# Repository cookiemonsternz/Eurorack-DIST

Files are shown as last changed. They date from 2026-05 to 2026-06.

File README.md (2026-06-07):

# DIST
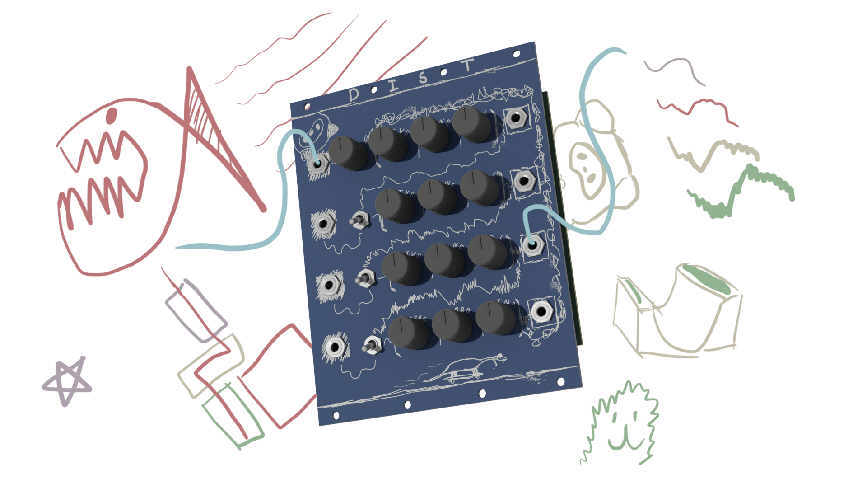
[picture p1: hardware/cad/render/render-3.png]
Render 3

_DIY multi-stage distortion Eurorack module, overdrive, distortion, fuzz, wrmergle, and any combination of them in one handy package_

#### What?
Where VCO was minimal, DIST is maximal! This is a module featuring four different distortion circuits, routed in series with inputs and outputs at every stage in the chain. The four circuits are:
1. Overdrive - Inspired by the Boss SD-1, but with a different tone section and diodes.
2. Distortion - Partly inspired by the RAT, again, many tweaks were made. 
3. Fuzz - Big Muff PI my beloved, slightly different architecture and transistors but still keeping the best tone section in effect I've seen.
4. Wrmergle - A fully custom, from scratch design based on internal feedback, with an adjustable noise gate for your convenience :)

Every circuit has a gain, tone, and volume control, as well as a switch deciding whether to take input from the previous section or from the input jack. The overdrive has a potentiometer instead of a switch, setting an overall feedback control for more fun effects.

#### Why?
Distortion is quite literally the best effect, but no one pedal gives quite enough for me lol. This module has various features which enable absolutely ridiculous gains, while still having some playability due to the noise gate. I also like the idea of having it patchable at any point, as it means you can pick and choose how much distortion (and of what types) you want, or even just use it as 4 seperate distortions in parallel. 

Its definitely a big module, but you do get an absolute crapton of features and control, which is always nice to have.

#### How to use?
The jacks on the left side are the inputs, and on the right the corresponding outputs.
Each section is routed into the next, and you can toggle between using the input jack or the previous stage as input using the switch. The top left knob controls the overall feedback, as in how much of the output of the WRMERGLE stage goes to the input of the OD stage. 

Generally, you should be able to find your way around by following the signal path on the front board.

#### Simulations
I've included the simulations I created on LTSpice; *od.asc*, *dist.asc*, *fuzz.asc*, and *wrmergle.asc* contain their respective distortion stages, *gate.asc* contains the gate circuit of the WRMERGLE section, and *structure.asc* is a pseudo-layout of the whole circuit (not functional).

There is also a livespice simulation of the OVERDRIVE section, but I opted not to further utilise this tool due to lack of cross platform support and performance limitations.

I've also included some audio samples generated through LTSpice in **audio-samples/**, note that these are simulations and are thus not perfect, but they should be reasonably accurate.

## Renders
Render 1
Render 2
Board Front
Board Back
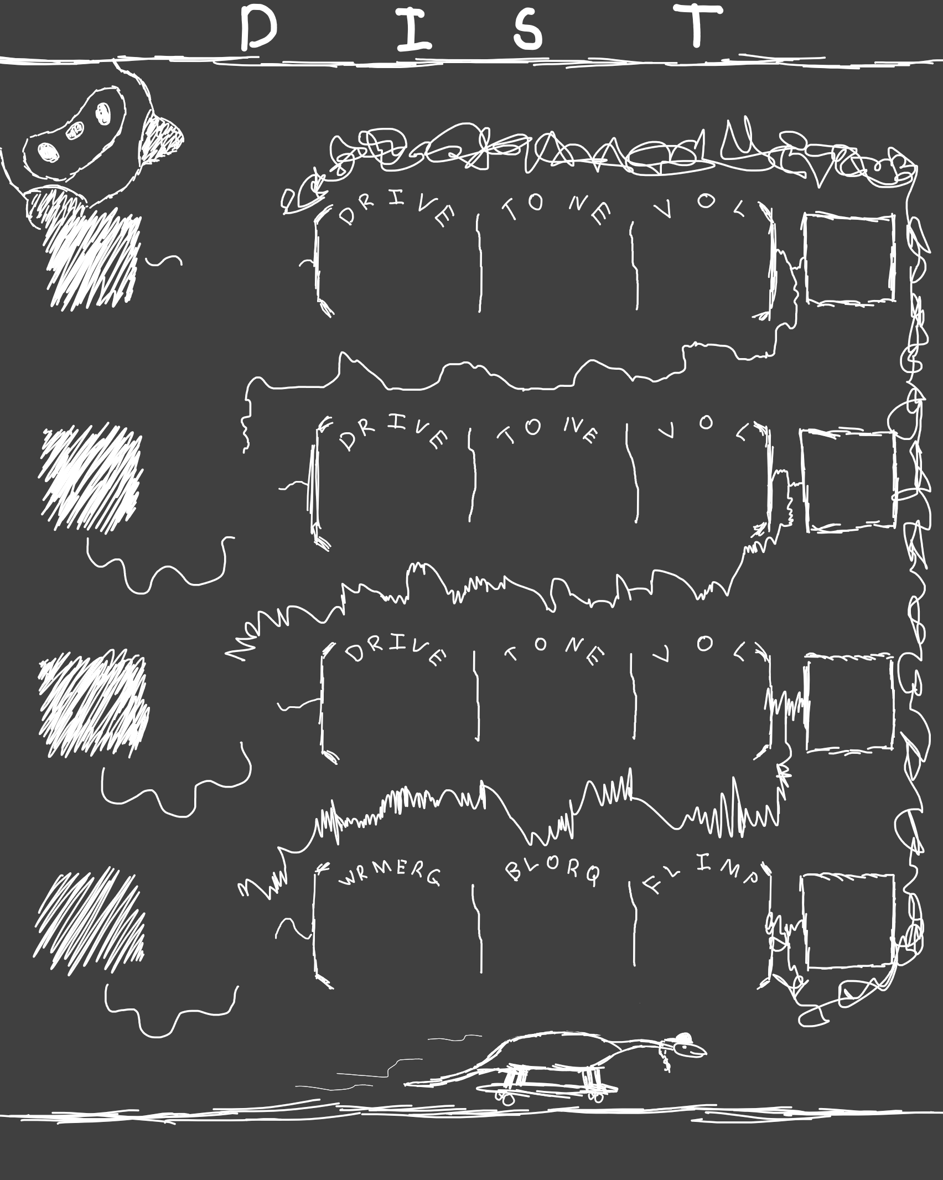
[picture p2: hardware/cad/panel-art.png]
Panel art


## Schematics
Main
OD
DIST
FUZZ
WRMERGLE

## Zine Page

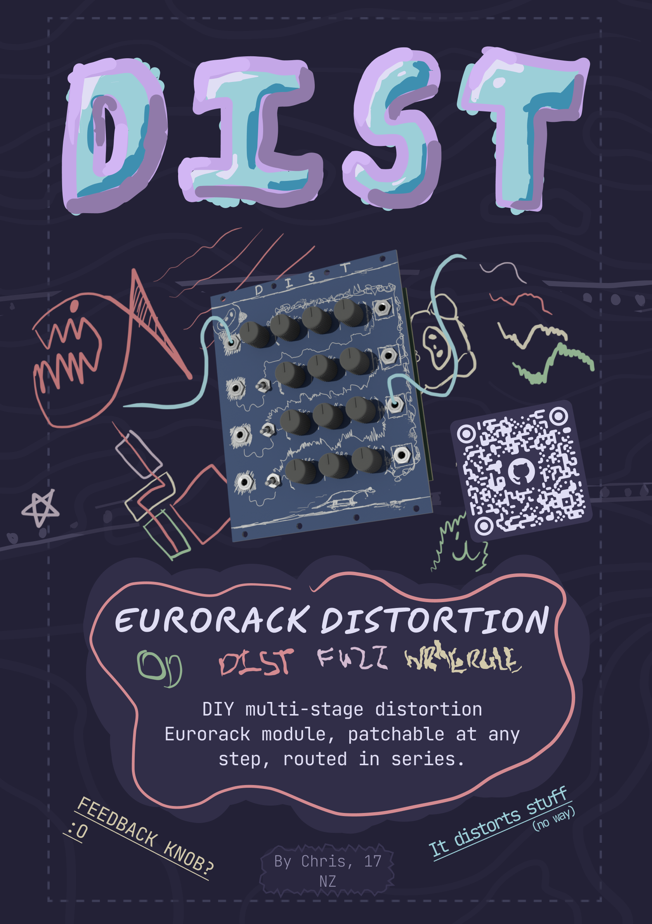
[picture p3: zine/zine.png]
Zine page


## BOM
_Needed is how many I personally need :)_
| Part | Quantity | Needed | Source | Link | Lot / Min Amount | Unit | Net | Running |
|---|---|---|---|---|---|---|---|---|
| **Capacitors** | | | | | | | | |
| 1n Cap, 0805 | 6 | 6 | JLCPCB | https://jlcpcb.com/partdetail/47657-CL21B102KBCNNNC/C46653 | 1 | $0.0112 | $0.0672 | $0.07 |
| 4.7n Cap, 0805 | 3 | 3 | JLCPCB | https://jlcpcb.com/partdetail/2096-0805B472K500NT/C1744 | 1 | $0.0066 | $0.0198 | $0.09 |
| 10n Cap, 0805 | 2 | 2 | JLCPCB | https://jlcpcb.com/partdetail/2062-CL21B103KBANNNC/C1710 | 1 | $0.0082 | $0.0164 | $0.10 |
| 22n Cap, 0805 | 2 | 2 | JLCPCB | https://jlcpcb.com/partdetail/2081-CL21B223KBANNNC/C1729 | 1 | $0.0097 | $0.0194 | $0.12 |
| 100n Cap, 0805 | 19 | 19 | JLCPCB | https://jlcpcb.com/partdetail/YAGEO-CC0805KRX7R9BB104/C49678 | 1 | $0.0066 | $0.1254 | $0.25 |
| 220n Cap, 0805 | 13 | 13 | JLCPCB | https://jlcpcb.com/partdetail/5810-CL21B224KBFNNNE/C5378 | 1 | $0.0122 | $0.1586 | $0.41 |
| 1u Cap, 0805 | 1 | 1 | JLCPCB | https://jlcpcb.com/partdetail/29074-CL21B105KBFNNNE/C28323 | 1 | $0.0165 | $0.0165 | $0.42 |
| 1u Electrolytic Cap, P1.5xD4.0 | 4 | 0 | LCSC | https://www.lcsc.com/product-detail/C216323.html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 | 50 | $0.0185 | $0.0000 | $0.42 |
| 2.2u Electrolytic Cap, P1.5xD4.0 | 1 | 0 | LCSC | https://www.lcsc.com/product-detail/C43343.html | 50 | $0.0151 | $0.0000 | $0.42 |
| 4.7u Electrolytic Cap, P1.5xD4.0 | 3 | 0 | LCSC | https://www.lcsc.com/product-detail/C2873979.html | 50 | $0.0114 | $0.0000 | $0.42 |
| 10u Electrolytic Cap, P1.5xD4.0  | 3 | 0 | LCSC | https://www.lcsc.com/product-detail/C503219.html | 50 | $0.0143 | $0.0000 | $0.42 |
| **Resistors** | | | | | | | | |
| 47? Resistor, 0805 | 2 | 2 | JLCPCB | https://jlcpcb.com/partdetail/18402-0805W8F470JT5E/C17714 | 1 | $0.002  | $0.0030 | $0.43 |
| 150? Resistor, 0805 | 2 | 2 | JLCPCB | https://jlcpcb.com/partdetail/18159-0805W8F1500T5E/C17471 | 1 | $0.0016 | $0.0032 | $0.43 |
| 560? Resistor, 0805 | 5 | 5 | JLCPCB | https://jlcpcb.com/partdetail/29388-0805W8F5600T5E/C28636 | 1 | $0.0019 | $0.0095 | $0.44 |
| 1k? Resistor, 0805 | 10 | 10 | JLCPCB | https://jlcpcb.com/partdetail/18201-0805W8F1001T5E/C17513 | 1 | $0.0021 | $0.0210 | $0.46 |
| 1.5k? Resistor, 0805 | 1 | 1 | JLCPCB | https://jlcpcb.com/partdetail/4717-0805W8F1501T5E/C4310 | 1 | $0.0015 | $0.0015 | $0.46 |
| 2.2k? Resistor, 0805 | 2 | 2 | JLCPCB | https://jlcpcb.com/partdetail/18208-0805W8F2201T5E/C17520 | 1 | $0.0015 | $0.0030 | $0.46 |
| 4.7k? Resistor, 0805 | 1 | 1 | JLCPCB | https://jlcpcb.com/partdetail/18361-0805W8F4701T5E/C17673 | 1 | $0.0016 | $0.0016 | $0.47 |
| 6.8k? Resistor, 0805 | 1 | 1 | JLCPCB | https://jlcpcb.com/partdetail/18460-0805W8F6801T5E/C17772 | 1 | $0.0017 | $0.0017 | $0.47 |
| 10k? Resistor, 0805 | 10 | 10 | JLCPCB | https://jlcpcb.com/partdetail/18102-0805W8F1002T5E/C17414 | 1 | $0.0020 | $0.0200 | $0.49 |
| 22k? Resistor, 0805 | 2 | 2 | JLCPCB | https://jlcpcb.com/partdetail/18248-0805W8F2202T5E/C17560 | 1 | $0.0027 | $0.0054 | $0.49 |
| 39k? Resistor, 0805 | 4 | 4 | JLCPCB | https://jlcpcb.com/partdetail/26569-0805W8F3902T5E/C25826 | 1 | $0.0018 | $0.0072 | $0.50 |
| 100k? Resistor, 0805 | 13 | 13 | JLCPCB | https://jlcpcb.com/partdetail/160838-0805W8F1003T5E/C149504 | 1 | $0.0020 | $0.0260 | $0.53 |
| 150k? Resistor, 0805 | 1 | 1 | JLCPCB | https://jlcpcb.com/partdetail/18158-0805W8F1503T5E/C17470 | 1 | $0.0018 | $0.0018 | $0.53 |
| 200k? Resistor, 0805 | 4 | 4 | JLCPCB | https://jlcpcb.com/partdetail/18227-0805W8F2003T5E/C17539 | 1 | $0.0021 | $0.0084 | $0.54 |
| 220k? Resistor, 0805 | 2 | 2 | JLCPCB | https://jlcpcb.com/partdetail/18244-0805W8F2203T5E/C17556 | 1 | $0.0017 | $0.0034 | $0.54 |
| 470k? Resistor, 0805 | 3 | 3 | JLCPCB | https://jlcpcb.com/partdetail/18397-0805W8F4703T5E/C17709 | 1 | $0.0015 | $0.0045 | $0.54 |
| 1M? Resistor, 0805 | 1 | 1 | JLCPCB | https://jlcpcb.com/partdetail/18202-0805W8F1004T5E/C17514 | 1 | $0.0010 | $0.0010 | $0.55 |
| 2.2M? Resistor, 0805 | 1 | 1 | JLCPCB | https://jlcpcb.com/partdetail/26856-0805W8F2204T5E/C26113 | 1 | $0.0033 | $0.0033 | $0.55 |
| **Diodes** | | | | | | | | |
| 1N4148WS, SOD-323 | 12 | 12 | JLCPCB | https://jlcpcb.com/partdetail/2485-1N4148WS/C2128 | 1 | $0.0092 | $0.1104 | $0.66 |
| **Other Components** | | | | | | | | |
| TL072CDT | 7 | 7 | JLCPCB | https://jlcpcb.com/partdetail/STMicroelectronics-TL072CDT/C6961 | 1 | $0.1570 | $1.0990 | $1.76 |
| 100k? Potentiometer, �RK09K� | 14 | 14 | Aliexpress | https://www.aliexpress.com/item/1005007278123055.html | 5 | $0.2080 | $3.1200 | $4.88 |
| SPDT Switch | 3 | 3 | Aliexpress | https://www.aliexpress.com/item/1005005370002265.html | 5 | $0.8520 | $4.2600 | $9.14 |
| PJ301M-12 Audio Jack | 8 | 8 | Aliexpress | https://www.aliexpress.com/item/1005004864182675.html | 10 | $0.4440 | $4.4000 | $13.54  |
| 2x08 IDC Connector | 1 | 0 | LCSC | https://www.lcsc.com/product-detail/C7430313.html | 5 | $0.0993 | $0.0000 | $13.54  |
| 100k? Trimpot, �3362p� | 1 | 1 | Aliexpress | https://www.aliexpress.com/item/1005010523079544.html | 10 | $0.4480 | $4.4800 | $18.02  |
| BC547B NPN BJT | 4 | 0 | LCSC | https://www.lcsc.com/product-detail/C713613.html | 10 | $0.0495 | $0.0000 | $18.02  |
| BSP89 N-MOSFET | 1 | 1 | JLCPCB | https://jlcpcb.com/partdetail/VBsemiElec-BSP89VB/C20755324 | 1 | $0.5565 | $0.5565 | $18.57  |
| **Other** | | | | | | | | |
| PCB | 1 | 1 | JLCPCB | NA | 5 | $1.6600 | $8.3000 | $26.87  |
| Aluminium Plate (100x200x2mm) | 1 | 1 | Aliexpress | https://www.aliexpress.com/item/1005007160296738.html | 1 | $6.2300 | $6.2300 | $33.10  |
| Total | | | | | | | | $33.10  |

| Totals | Money  |
|---|---|
| Aliexpress, Inc. Shipping + Tax | $24.57 |
| JLCPCB, Inc. Shipping + Tax | $38.84 |
| Total | $63.41 |

## CAD Links
Heres the links to the CAD source, Onshape:
[Panel source](https://cad.onshape.com/documents/a7eabe2ba59f8201542a9705/w/4e0a52924acb1733bd85ab30/e/c5b387347f991d36168a8bde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)

## Directory Structure
- **audio-samples/** - Generated audio demos of each subcircuit, through ltspice
- **hardware/**
    - **bom/** - BOM Files (CSV and LibreOffice Calc)
    - **cad/** - CAD Files
        - **render/** - Files for rendering (inc. gltf models)
    - **dist/** - KiCad files
        - **lib/** - External libraries
        - **production/** - Production files (Gerber, etc.)
    - **livespice/** - LiveSpice electrical simulations
    - **ltspice/** - LTSpice electrical simulations
- **journals/**
- **zine/** - Zine page

## References
Circuit design influenced by:
[Electric Druid Classic OD](https://electricdruid.net/designing-a-classic-overdrive/)
[Boss SD-1](https://www.hobby-hour.com/electronics/s/sd1-super-overdrive.php)
[RAT](https://www.electrosmash.com/proco-rat)
[Big Muff PI](https://www.bigmuffpage.com/Big_Muff_Pi_versions_schematics_part1.html)
[One Knob Noise Gate](https://effectslayouts.blogspot.com/2016/07/one-knob-noise-gate.html)

#### This project was created for [Hack Club](https://hackclub.com/) - [Fallout](https://fallout.hackclub.com/)

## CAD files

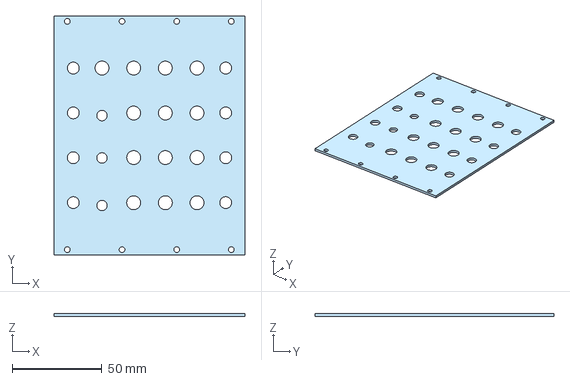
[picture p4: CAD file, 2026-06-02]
hardware/cad/panel.step
106.5 x 133.2 x 1.59 mm

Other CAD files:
hardware/cad/panel.dxf
hardware/cad/render/assets/models/rollerball-pen_c3ec9686-dba6-47c4-9347-b431545f39ef/rollerball-pen_2K_195a9d5d-4d1e-48a2-91c0-f7ec95fa4b7c.blend

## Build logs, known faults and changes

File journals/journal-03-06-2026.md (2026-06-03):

# DIST Journal 8 - 03/06/2026

Guess what!
It's tomorrow now :)

First things first, the readme.
Following the same layout as every other project I've made, pretty much done atp, just need to add the bom and zine:
README

Next up, finishing off the BOM:
Totals

biit pricy but like literally half the cost is in shipping, and theres no way I'm getting that cheaper lol.

And last but certainly not least, the zine page!
Zine page
And I mean, it is pretty much a straight clone of the other one, but they are a series so its kinda deliberate yknow? Hopefully its fine, can't see why it wouldn't be.

Last thing I want to do before going through some checklists is to swap over to linux and generate some more audio samples for wrmergle and od, as those don't have samples for all three inputs.

---

Ten minutes later and thats all done now as well, now just need to go through the checklist :)

---

And yep, pretty sure its all good :) Gonna just go and submit it now and also chuck it in the slack channel for people to double check (press x to doubt).

Sooooo, I guess goodbye until I get to building this <3

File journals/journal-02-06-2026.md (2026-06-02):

# DIST Journal 7 - 02/06/2026

Hello and welcome back! Off school today because sick so its time to absolutely lock in :)

To repeat the goals I set from yesterday:
- [ ] Check about changing R64 from 2.2M to 1M, simulate (in noise gate)
- [ ] Board Outline
- [ ] Layout PCB
- [ ] PCB Mount Hole/s
- [ ] Route PCB
- [ ] Panel Outline
- [ ] Panel Art

---

First up, board outline :)
Looking at one sections layout, it'll be approximately 80mm wide, and I'll want a bit of margin, so I'll go for ~90mm

Snapping that to eurorack standards, and it'll be 18hp wide, or 91.44mm, and the height, as always will be 3u, or 133.35mm.

For the actual PCB, I'll go with 87.5mm wide to give a touch of clearance, and 100mm tall to fit between the mounting rails.

Soooo, I just need to fit all of the components in here:
Board outline
Should be easy as pie :)

Gosh darn it I forgot to account for the switches >:(
Board will need to be an extra 15mm wide i'll say, so 21hp or 106.68 for a pcb width of 105mm.
And heres the actual layout of the top:
Top layout

Time to get into the actual layout :)

Overdrive section:
Overdrive section
I'd like to space out the components a bit more, just so its easier to swap / repair later when the need arises. 

Arrggh I'm really wanting to swap to 0603 / 0805 resistors now. This is quite annoying, bc I definitely have space for it and it will make hand soldering much much easier, but it means I need to redo a bunch of the bom. fork my chud life >:(

I'll do it :(, more hours won't hurt lol

---

And after like 15 mins its done (again :3). Bonus is that there is a 2.2MOhm resistor in 0805, so don't need to swap it to 1M :)

Anyways, updating the layout:
layout w/ 0805
Defo still gonna fit easily lol.

Will have to redo a bunch of the OD section but it should be pretty quick :)
OD Section redo
I was right, twas very quick :)

Next up the distortion section, which should be a similar story.
Distortion section

And then fuzz:
Fuzz
Bit more involved but still easy as pie

And finally, the wrmergle section;

---

Interjection! Most of the way through it now but turns out I mucked up the potentiometers :(, forgot to have the noise gate one as a trim pot and the other one is just a header for some reason. Updating the bom and the thing now :)

Annnd done :)
Wrmergle Section

All thats left now is the filter caps by each op amp, and then routing power :)
Power routed
Easy peasy :), done :O, now just need to sort out drc errors

annd after replacing every single via with one that is 0.05mm larger, I'm done :)

Now just to sort the silkscreen, looks quite messy atm lol.
Front
The front of the pcb doesn't need to look fancy or anything, bc you'll never see it, even when the module is out of the rack its still covered by the front plate.

For the back silkscreen, I made it mostly tidy-ish to read, so you should be able to assemble this by hand / repair it easily enough, and I also accented all the hand soldered parts :)
Back silkscreen

There are also a couple spots to chuck some art if I want, which could be a fun addition later but for now i'll leave it.

---

Quick progress review:
- [x] Board Outline
- [x] Layout PCB
- [x] PCB Mount Hole/s
- [x] Route PCB
- [ ] Panel Outline
- [ ] Panel Art

I probably won't use mount holes on this board, theres a pretty even distribution of components which should easily hold it firmly.

I also quickly took the liberty of adding 3d models to everything, so heres some of that:
Front

Back
Looks pretty good colon three

---

Next up, the panel!
Again I'm going to just order an aluminum panel and cut some holes in it, but I'll model it up in onshape quickly :)

Front panel
Lots of wacky measurements but whatever lol :)

And in 3d:
Front panel
All lining up well :) well, the pots are a bit off but I'm fairly certain its the 3d model i'm using, and even if it isn't i'll measure properly before i drill.

Quickly exported everything as well

---

Next up, some panel art!
Before I get to that though, I'd like to bring everything into blender to get all the nuts and stuff on, and then bring a screenshot of that into krita to draw around.

I'll just chuck a buncha in progress images here:
Progress 1, connecting lines

Progress 2, labels

Progress 3, Soup and dino :)

And done:
Panel art final :)

Bringing it into blender:
Blender version

And some renders:
Render 1
Render 2

And one for the zine, using the same palette as last time because yknow, its part of a series :)

Render 3

Not much left to do now lol, just the readme and zine :)

And I reckon those'll be a tomorrow job, its late im tired and still sick and i dunno if I have the day off school tmmrw.

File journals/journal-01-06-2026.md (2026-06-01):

# DIST Journal 6 - 01/06/2026

Woah
20 days left thats crazy
Anyways time to lock in :)

---

My goal for today is to get the pcb done, and potentially also the plate, hell if I can i'd like to finish the whole project but we'll see lol.

First things first, assigning a buncha footprints. As I go through this I'll also chuck everything into a bom.

---

Waiit I'm such an idiot, i totally forgot I'm making a eurorack module, not a pedal T-T
I put a dc barrel jack connector for power lol, eurorack uses a 8 pin idc conn :O.

Hmmmm this might require a bit of rethinking. Eurorack power has a dual supply, so -12, gnd, and 12v, whereas I designed my system to have gnd and 24v. This means that I shifted all of my signals to +12v (BIAS) so that it was within the op amp supply range.

Hmmmm how to fix, can't just connect eurorack ground to my bias and eurorack vss to my gnd bc then all my connector shielding will be at -12V, unless I change it obv.

Ok the circuit is actually fundamentally the same, it's just that in my original conception, the signals were around the negative supply, whereas here they're around bias. Hmmm this should be relatively easily fixable, just need to go through logically and check all the sections. Might even be able to drop some of the buffering :) 

I am going to swap back to linux just because it's much nice to do ltspice there. See ya in a minute :)

---

Hello from linux :)
Getting straight back into it and I'm gonna start by trying the OD circuit.

And yeah, pretty easy: Op amps stay at the full supply range (VSS-VDD) and everything that would be going to BIAS goes to GND. Sounds identical to me so I reckon its all good :)
OD CIrcuit dual supply

Similar thing here, replace all the BIAS and most of VSS with gnd (just excl the op amp supplies) and it just worked off the bat.
DIST Circuit dual supply

And then the fuzz circuit:
Fuzz circuit dual supply

And finally, the wrmergle circuit:
WRMERGLE Circuit

I'm going to go through everything and see what I can clear out. Theres a bunch of stuff that I put to pull stuff up to BIAS, that won't be needed anymore as everything is around ground.
Overall managed to clear out like 6 sections, not as much as I had hoped but still decent. I should also be able to clear out a bit from the structure as well :) 

---

Ok after a bit of research, I should be able to drop all of the input buffers given I increase the impedance of the input filtering stage. This basically just means making sure all of the resisters are big-ish on the input :)

And heres the updated structure:
Structure

Righty ho, time to get back to windows and chuck my changes into KiCad :)

---

Ok back on windows! Did a bit of mixing on a song but time for electronics again!

Annd after a wee bit of work its all updated in KiCad :)

Would give screenshots but yknow, not much different to the above lol.

---

Now finally onto footprint assignment ...

Going through and its been pretty chill so far, only things I've mainly changed is some values of stuff, eg 40k to 39k resistors just because its what JLC has and it wont make a major difference. 

For all the electrolytic capacitors, I'll be using my own stock, which is all d4xp1.5 tht, so thats easy enough. (had to measure them which is why i was a bit inactive in the lapse)

One thing is I want to change the 2.2M Ohm resistor (R64, in the noise gate) down to 1M Ohm, as thats a basic part in jlc. I'll need to simulate this but I'm pretty sure it'll be fine, just might affect the gate trimming slightly.

And after a bunch more work, I have my pcb parts bom done! Total of ~$13 so far, not too shabby :)
_Urggh hc cdn isn't working :( time to go upload to github >:(_
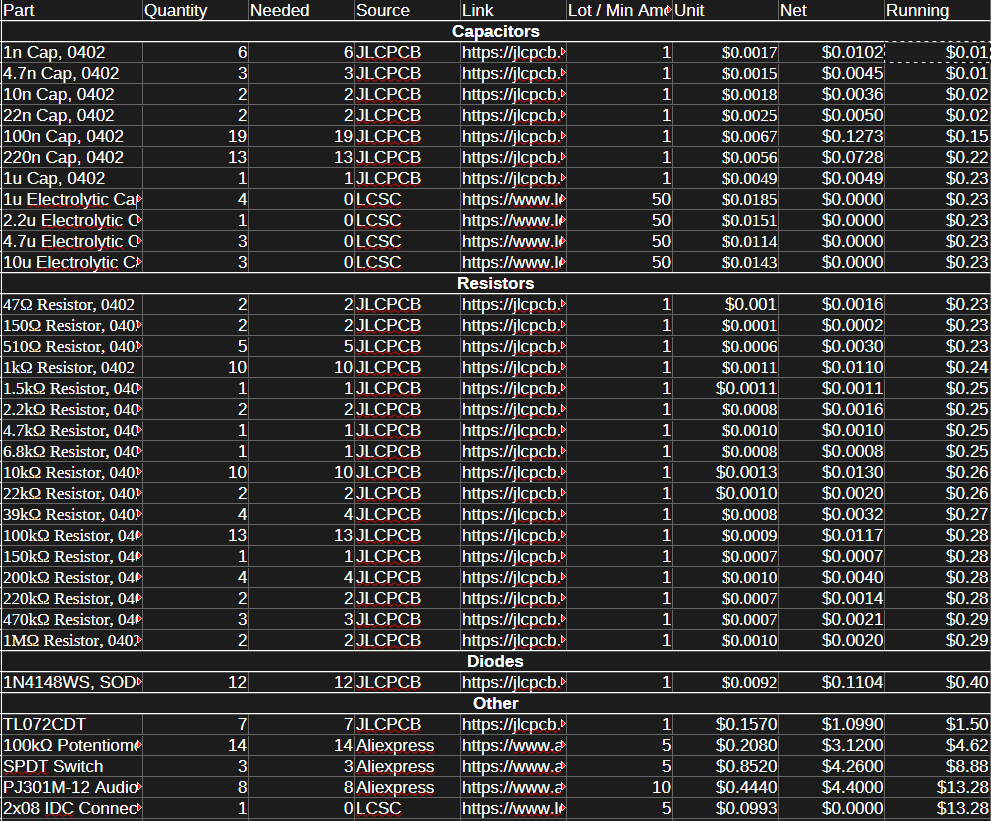
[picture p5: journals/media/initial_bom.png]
Initial Bom


Annd bringing it all into an actual layout...
![PCB view on import]([image.png](https://raw.githubusercontent.com/cookiemonsternz/Eurorack-DIST/refs/heads/main/journals/media/un-layed-out-pcb.png))
Not too bad at all, I can definitely work with this :)
I might have all my pcba components on the back and then just the jacks and stuff on the front again, just to save a little space

To end off today, heres my todo list. I'm going to aim to have all of this complete by the end of tuesday, the 3rd:
- [ ] Check about changing R64 from 2.2M to 1M, simulate (in noise gate)
- [ ] Board Outline
- [ ] Layout PCB
- [ ] PCB Mount Hole/s
- [ ] Route PCB
- [ ] Panel Outline
- [ ] Panel Art
  
bis spater!

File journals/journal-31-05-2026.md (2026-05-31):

# DIST Journal 5 - 31/05/2026

Wellp its been a hot minute! I've been taking a wee break from stuff for the past wee while because reasons (was locked in gaming lol), but I've just submitted my drone so this is my only ongoing project atm, and I reckon its about time to do a bit more work on it :)

When I last left off, I was sorting out the buffering between sections, so I'll just finish that off now :)

It's a tiny bit of a pain, but essentially, I need to shift the voltage up to BIAS and then after buffering I pull it back to swing around ground. Means a few more components which is annoying but I'm pretty sure its the only way. I could go without buffering but it could have unintended effects if the impedances are weird.-

---

Quick pause, lookout was being really weird on linux, so I've swapped over to windows. Unfortunately LTSpice is being super weird, but I have come across a new program I would very much like to try out, LiveSpice, which is ltspice but for audio specifically. Supposedly it works to the point of live simulation but tbh I just want to use it for ease of use, theres less setup and all the common components are baked in :)

---

Annnd after a wee bit of troubleshooting, I now have the OD Circuit recreated and functional :) Its cool how its able to do it pretty much realtime, but it can get rather choppy with higher oversampling.
Livespice recreation version

Anyways, very cool but I imagine its certainly not going to be fast enough to model the full circuit. I'm just gonna do a simplified mockup version :)

Heres the final layout:
Combined mockup

I haven't included the actual circuits here and it is obviously more of a pseudo circuit than actual (definitely won't simulate) but it is correct (I hope). At each stage (excl. OD) you can swap between the output of the previous stage or a seperate input port. Theres also a feedback from the end of the chain to OD. Only thing I need to watch out for is that I now need to make sure each circuits output swings around the bias voltage, and then it will be buffered and referenced to ground.

Apologies for it looking ugly, I haven't set up my theme for LTSpice on windows yet :(

Time to get this into KiCad! 

---

Starting off with a tricky question, what do I want to do for op amps?
I need a total of 18, but how I distribute them is up to me (TL071, TL072, TL074, just the different versions of the chip with different numbers of chips on them). I think I am going to go SMD for this one, simply due to the sheer number of components and the required board size were I to try THT, so I'll have a look on lcsc and see whats cheapest / easiest. Only other consideration is how tricky it'll make routing, TL072's would probably be simplest.

... annnd guess what we're using? That's right! It's the TL072. Not only easiest to route but its also available as a basic part for pcba, which is quite appealing to me :)

---

After a wee bit of schematicising, I have the main section pretty much done:
Main section

Obviously missing the main power section for now, but overall its pretty complete-ish.

Next up, the overdrive :)
Overdrive circuit

Then the distortion:
Distortion circuit
_Note to self, check whether I need the pulldown to bias in input scaling, C21 + R23_

And the fuzz:
Fuzz circuit

And finally the wrmergle:
WRMERGLE Circuit
Bit of an ugly looking schematic but whatevs, i'll live :)

And then the wee power supply section:
Power supply section
I'm just double checking this design by asking on the slack, but i'm pretty sure its fine. My only concern is whether the leakage current through the schottky diode will be enough to damage the electrolytic cap, but my gut tells me it won't be a problem sooo. Either way, I'll probs make the diode and cap tht just for the sake of repairability just in case.

Annd thats the full schematic done :)
I think I will go with pcba, as I have virtually no smd components which won't be basic, so it should be pretty cheap.

I'll try for a two layer board for the sake of costs, but 4 layers is only an extra five bucks so if its proving too difficult i'm not too bothered.

I reckon I'll wrap it up here for tonight. Gotta get my beauty sleep (jk im so freaking sick and i don't wanna have to cancel dnd tmmrw, maybe more sleep will help :O)

Gn reviewer <3

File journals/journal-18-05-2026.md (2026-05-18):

# DIST Journal 4 - 18/05/2026

Hello again!
I've done some untracked work and have the circuit for the final distortion thing pretty much done.

I'll give a quick run through of what I settled on.

---

First up we've got the input stage, which is all but identical to all the other circuits, except with a high pass tuned to ~140Hz.
Input stage

Next up, the clipping:
This is the same core clipping circuit as in the overdrive, but I've added a configurably feedback path to act as the drive amount.
Clipping stage
This gives a very cool distortion but also constant feedback, which isn't ideal, which is where my next plan comes in, but unfortunately that is not yet implemented.

Anyways, the tone section is just stolen from the big muff pi:
Tone section

And then finally some buffering and filtering to take us back up to eurorack voltage, as well as a simple volume control.

Buffering and volume section

Now for my secret weapon!

---

My idea to prevent horrible feedback is to just include a noise gate, where the source signal controls the gate on the distorted signal. Ideally this should clamp the output shut when the input is low and thus no feedback.

I found a schematic online, and did some work to convert it such that my input can be different than the gate input:
Gate circuit

The pink signal is modulated by the blue one, where blue drops out, so does pink. The light blue is the gate, once this reaches a threshold of a bit over 0v, it cuts out the main input.

I have massively shrunk the capacitors for this demonstration, so it comes on and off quite agressively but the point stands.

And after a bit of trial and error, I've come up with this:
Noise gate in contex

It 100% sounds better than before, so thats amazing, very happy with this addition. In order to get it to have a good degree of reduction, it does eat up quite a bit of current however. I've currently dialed it to ~20mA but I might reduce this in the future.

[Before](./media/wrmergle-output-before) | [After](./media/wrmergle-output-after.wav)

---

And that pretty much wraps up all the distortion circuits.

Only thing left to do is properly chain them all together :)

I'll try doing this in one ltspice file but I'm not super hopeful lol, might just be a case of winging it.

---

Hmm, i've chucked them all into one file (not connected up yet) and it is a hell of a lot of components lol. Might have to go smd for this one.
Full circuit

And now its mostly wired up:
Full circuit connected

I'm trying to simulate it but it is very very slow, like maybe an hour long thing, so I'll just hope that its good (i mean I can't see why it wouldn't be).

!! NEVERMIND THATS FALSE I NEED TO BUFFER W/ BIAS :( !!

Tomorrow job am tired and probs sick.

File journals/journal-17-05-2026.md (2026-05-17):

# DIST Journal 3 - 17/05/2026

First things first today, chucking the circuit from yesterday into the simulation.

---

## OD

First step in this was getting basic audio input and output from ltspice, which was reasonably simple, just specify an output and an input wav file and it just works :)

LTSpice audio input / output

---

Alright I chucked together the first bit of the circuit and was really confused why it wasn't working. I was using a 1m resistor instead of 1Meg :( god thats stupid.

And after a tiny bit more troubleshooting (I'd flipped the voltage supplies on the op amp somehow) I've got a pretty decent result:

Full circuit

It honestly sounds really good for a simulation, and I expect reasonably accurate to real life. 

And now with proper input voltage and output voltage scaling to eurorack standards (+-5V):
Proper

And after a bit of tidy up, I'm happy to call the OD circuit complete :)

tidy circuit schematic

---

I suppose I should probably mention at some point the main ideas behind this module.
I quickly sketched out the layout while on a road trip so heres that:

Module layout

Basically, we input into the OD, and then can run it into the next etc etc. At the input of every module, we have a switch to swap between the output of the previous module or a new input. 

At the end of the chain there is a feedback path just for fun :)

Annyyways, next up is a wee distortion circuit. I think I'll model this one on the RAT pedal, a classic distortion that I quite like the sound of.

---

## Distortion

We start with some basic input filtering, same as in the OD circuit, just a highpass filter set at 7Hz and some scaling down to typical guitar-ish level input ranges instead of the eurorack +-5V:

input stage

The reference circuit then had a filter set at 172kHz, which also helps to prevent overcurrent to the op amp. I've subbed this out for one at a more reasonable 32kHz, just to remove all energy we don't need from the signal, while still keeping the overcurrent protection.

Filter

Next up, the clipping stage, which is rather similar to the overdrive's clipping stage. The main difference is the clipping diodes shunt to VSS, instead or being placed in the op-amp feedback path. This is generally the main difference between overdrive and distortion. Overdrive will clip softly, rounding out sharp edges, while distortions clip sharply, chopping off bits of the waveform.

Clipping section

It is worth noting that the original rat used an LM308 op amp, while here I am modelling a TL072. The tl072 op amp has a much faster slew rate than the LM series, so there will be a much greater distribution of higher harmonics. I'll try filtering these out, but if it comes to it I do have some LM series op amps lying about so I can try those as well.

The RAT's tone control is quite literally just a low pass filter, tuned to provide a range of about 375Hz - 37kHz.

Tone Section

And finally some output scaling. The original RAT used a JFET buffer because it used the LM308 op amp, which is too slow to properly buffer audio signals with 20kHz range, but given I'm using the TL072, I can just use this. Unfortunately, I do have to shift the voltage back up to be centered around the bias voltage, but this isn't too big of a deal. Anyways, here is the output buffer and volume control section:

Output section

And that gives us the completed distortion circuit:
Distortion circuit

And welp it's definitely distorting stuff:
Heres the [input](./media/dist-input-1.wav) and [output](./media/dist-output-1.wav). Certainly something, though I'd like to try it with a different source audio I think.

Heres with bass guitar:
[input](./media/dist-input-2.wav) | [output](./media/dist-output-2.wav)
And some electric guitar:
[input](./media/dist-input-3.wav) | [output](./media/dist-output-3.wav)

Overall not too shabby. I am going to try it with the LM308 quickly though and see if I prefer the sound of that.

Welp I tried it and it sounds pretty identical to me, so I'll just stick with the TL072 for now. I'll try it on the breadboard but that'll have to wait till later.

---

## Fuzz

Next up, a fuzz circuit. This will be modelled off my goat the Big Muff Pi, albeit only roughly.

First up, the input section.
While the real circuit uses a common emmiter amplifier, I'm going to go with an op amp based input circuit, and just chuck some filters on it.

First up the filtering, this is the same case as in the last couple ones, first divide the voltage down to guitar levels, then a ~7Hz high pass and then a low pass, here tuned to around 1kHz (to be roughly accurate to the real circuit).
Pre stage

Next up we need amplification of around 10x, which can be achieved with a simple non-inverting amplifier configuration.

Scaling

And then some adjustable scaling before the actual clipping section, this is effectively the drive control.
Drive control

For the actual drive circuit, BC239 transistors are used, but these are very similar to the much more readily available BC547 transistors (which I also have on hand) so I'm using those instead.

I was a bit worried that the different voltage would stuff up the transistor stages but from what I can see its fine. I'll think through why later lol. Anyways, heres the first clipping stage:
Clipping stage A
This provides a more light distortion, before hard clipping in the next stage, which is an identical circut.

The tone section of this circuit is quite smart, just a low pass and high pass filter being simultaneously controlled by a single knob. Might use this in the future lol.

Tone control

And then to finish it off a basic wee output stage. In the original circuit, they yet again used a common emitter amplifier, and as before, I'll just use an op amp.
After scaling it up, I'll just chuck in a basic volume control as with all the other circuits.
output

And with that, this circuit is also done :)

Full circuit

Heres some audio demos:
Guitar:
[Input](./media/dist-input-3.wav) | [Output](./media/fuzz-output-1.wav)
Bass:
[Input](./media/dist-input-2.wav) | [Output](./media/fuzz-output-2.wav)
Songy thing:
[Input](./media/dist-input-1.wav) | [Output](./media/fuzz-output-3.wav)

Verryy nicce :)

Only one more stage now, but I think I might leave that for tomorrow :O
Not to spoil anything, but I'm planning on a custom design with a couple stages and some immense gain lol, just completely breaking up the signal.

Annnyways, been a good session today, lots of things done. Bis spater :)

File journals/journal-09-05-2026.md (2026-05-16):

# DIST Journal 1 - 09/05/2026

Well! It's time for the not-so-long awaited sequel to VCO: DIST.

This is going to be a distortion eurorack module, not entirely sure what / how its gonna work but that's what today is for!
Overall very excited for this project, I've done a bit of distortion stuff before but this will be on a whole other level. I think for this one, my process will also be slightly different; i'll likely do a bit less sim work and more prototype sections on the breadboard, as seeing how things sound is quite important for distortions.

Before I move onto the design requirements, I'd like to take a little bit of a look at other eurorack distortion modules, just to get a wee bit of an idea of how they do it.

Welp, I've had a brief look at some modules and I think I'm ready to do some requirements :)

## Design Requirements

- Versatile (In the usable sense) - Wacky distortions are cool and all, but first and foremost I need something that can do all the basic sounds, pretty much just can do overdrive and medium distortion.
- Multi stage - I really like the idea of how the Noise Engineering Terci Ruina does it, where you can input at the start of any stage and output at the end of any stage.
- Tone adjustable - Really just need some filtering / eq on board, I really enjoy pedals which have this

---
Those are pretty much all my super basic requirements, the following are optional but I'd quite like to have them.

- Can do heavy distortion - I quite like distortions with insane levels of breakup, so that could be quite fun to include.
- Visual feedback - Could be fun to have like an led or something, might not be worth the effort though lol
- Fun feature - Just something that sounds funky idk what yet, maybe a phasy thing?

## Design

I do want to make a bit of a start today, so I'm going to look at the first stage of this distortion, which will be a light overdrive. I'm going to have a look at a couple different circuits and structures, and see which ones appeal to me.

Welp I've gotten a schematic from online and modelled it up, and it does seem to be sort of working, only clipping one half but I assume thats because I've converted the circuit improperly, as its running of a single supply and my module will be running off a dual supply.
OD Circuit v0

I do really need to sleep unfortunately so further work on this will have to wait until another day :(
Bye bye!

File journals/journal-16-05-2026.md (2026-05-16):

# DIST Journal 2 - 16/05/2026

Guess whos back! Its me :)
Working some more on this project because I need to do bom work for the drone and I don't feel like that lol. 
Today I'm gonna try to get the sim properly working with the dual supply.

---

righty ho I did a bunch of irl breadboarding instead which was fun. Got a decent sounding overdrive which I'll translate into the sim later :)

Took a bit of tweaking, as the schematic I was following had really weird gain values (or at least I thought it did lol, turns out i'd put a wire in the wrong place and it was just getting the signal through supply noise lol), and also was very noisy so I chucked a bunch more power supply filtering. 

In the end theres still a bit of noise that I've still got to chase down, but otherwise very happy with it. Uploaded a audio demo:
[Audio sample](./media/sample.wav)
Audio sample (as video)

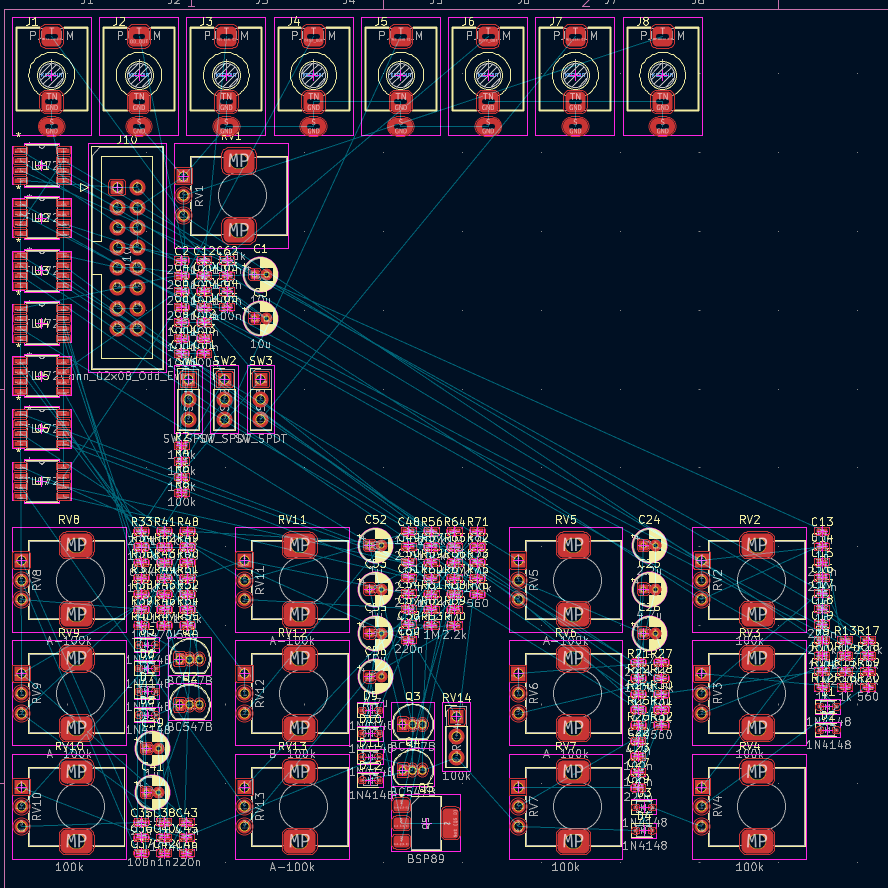
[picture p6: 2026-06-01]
journals/media/un-layed-out-pcb.png

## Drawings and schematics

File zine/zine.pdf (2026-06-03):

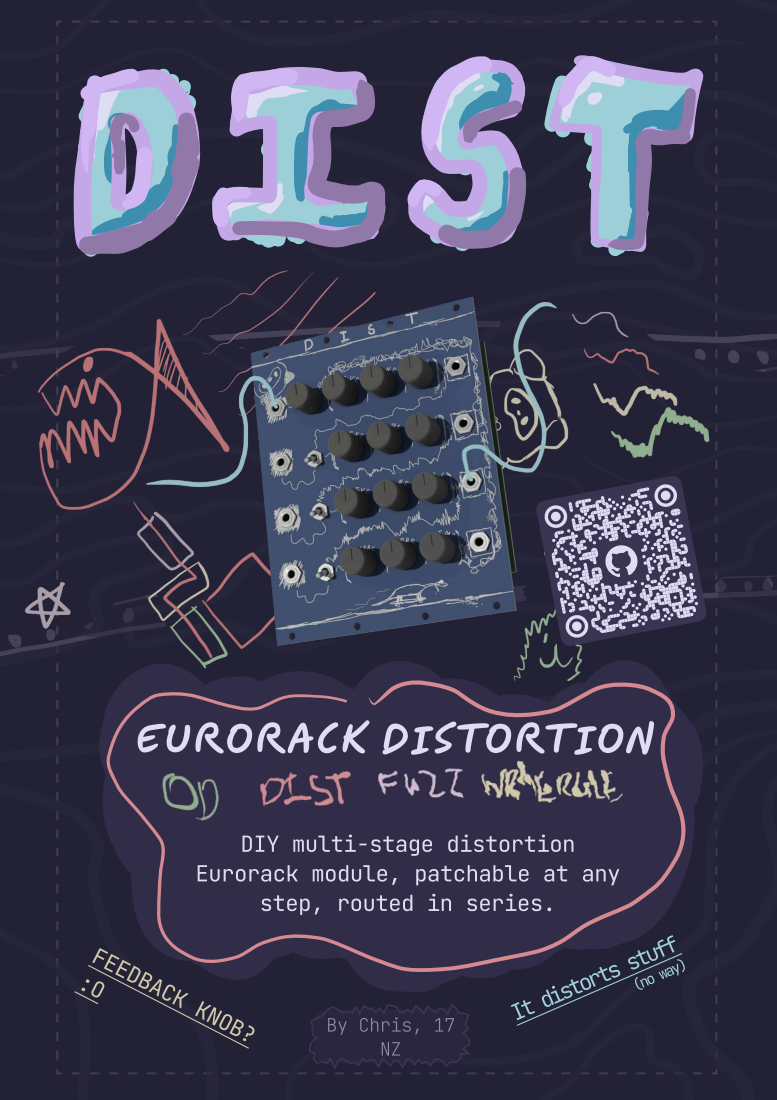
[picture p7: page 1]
EURORACK DISTORTION; FEEDBACK KNOB? :O; By Chris, 17 NZ

DIY multi-stage distortion
Eurorack module, patchable at any
step, routed in series.

It distorts stuff
(no way)

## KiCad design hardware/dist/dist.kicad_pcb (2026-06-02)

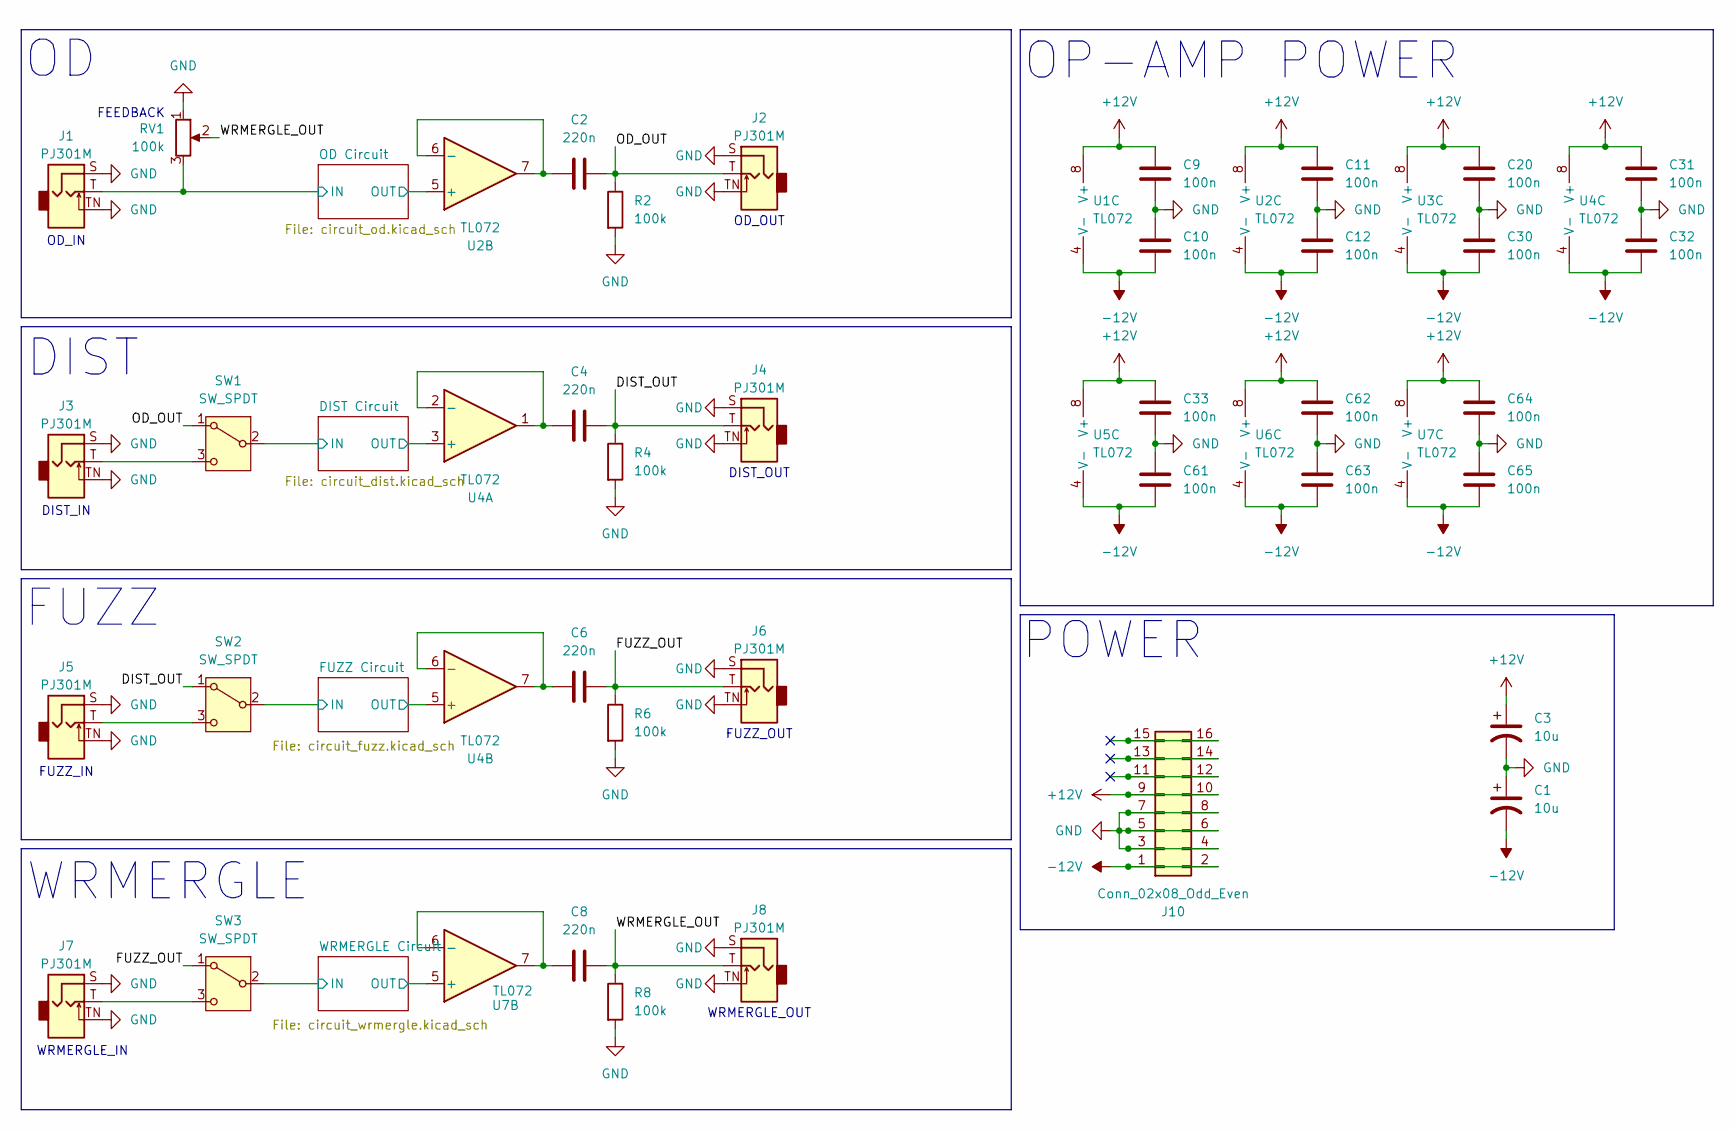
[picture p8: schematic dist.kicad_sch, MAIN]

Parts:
C1, C3: 10u; CP_Radial_D4.0mm_P1.50mm
C2, C4, C6, C8: 220n; C_0805_2012Metric_Pad1.18x1.45mm_HandSolder
C9, C10, C11, C12, C20, C30, C31, C32, C33, C61, C62, C63, C64, C65: 100n; C_0805_2012Metric_Pad1.18x1.45mm_HandSolder
J1, J2, J3, J4, J5, J6, J7, J8: PJ301M; Jack_3.5mm_QingPu_WQP-PJ301M-12_Vertical
J10: Conn_02x08_Odd_Even; IDC-Header_2x08_P2.54mm_Vertical
R2, R4, R6, R8: 100k; R_0805_2012Metric_Pad1.20x1.40mm_HandSolder
RV1: 100k; Potentiometer_Alps_RK09K_Single_Vertical
SW1, SW2, SW3: SW_SPDT; PinHeader_1x03_P2.54mm_Vertical
U1, U2, U3, U4, U5, U6, U7: TL072; D8_TEX_STM

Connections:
+12V: C3.1, C9.1, C11.1, C20.1, C31.1, C33.1, C62.1, C64.1, J10.9, J10.10, U1.8 (V+), U2.8 (V+), U3.8 (V+), U4.8 (V+), U5.8 (V+), U6.8 (V+), U7.8 (V+); also elsewhere on the board
-12V: C1.2, C10.2, C12.2, C30.2, C32.2, C61.2, C63.2, C65.2, J10.1, J10.2, U1.4 (V-), U2.4 (V-), U3.4 (V-), U4.4 (V-), U5.4 (V-), U6.4 (V-), U7.4 (V-)
/DIST Circuit/IN: SW1.2 (B); also elsewhere on the board
/DIST Circuit/OUT: U4.3 (+); also elsewhere on the board
/DIST_OUT: C4.2, J4.T, R4.1, SW2.1 (A)
/FUZZ Circuit/IN: SW2.2 (B); also elsewhere on the board
/FUZZ Circuit/OUT: U4.5 (+); also elsewhere on the board
/FUZZ_OUT: C6.2, J6.T, R6.1, SW3.1 (A)
/OD Circuit/IN: J1.T, RV1.3; also elsewhere on the board
/OD Circuit/OUT: U2.5 (+); also elsewhere on the board
/OD_OUT: C2.2, J2.T, R2.1, SW1.1 (A)
/WRMERGLE Circuit/IN: SW3.2 (B); also elsewhere on the board
/WRMERGLE Circuit/OUT: U7.5 (+); also elsewhere on the board
/WRMERGLE_OUT: C8.2, J8.T, R8.1, RV1.2
GND: C1.1, C3.2, C9.2, C10.1, C11.2, C12.1, C20.2, C30.1, C31.2, C32.1, C33.2, C61.1, C62.2, C63.1, C64.2, C65.1, J1.S, J1.TN, J2.S, J2.TN, J3.S, J3.TN, J4.S, J4.TN, J5.S, J5.TN, J6.S, J6.TN, J7.S, J7.TN, J8.S, J8.TN, J10.3, J10.4, J10.5, J10.6, J10.7, J10.8, R2.2, R4.2, R6.2, R8.2, RV1.1; also elsewhere on the board
unnamed: J3.T, SW1.3 (C)
unnamed: J5.T, SW2.3 (C)
unnamed: J7.T, SW3.3 (C)
unnamed: C2.1, U2.6 (-), U2.7
unnamed: C4.1, U4.1, U4.2 (-)
unnamed: C6.1, U4.6 (-), U4.7
unnamed: C8.1, U7.6 (-), U7.7

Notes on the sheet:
DIST_OUT
OD_OUT
FUZZ_OUT
WRMERGLE_OUT
FUZZ
WRMERGLE_IN
FUZZ_IN
DIST_IN
WRMERGLE
OP-AMP POWER
POWER
OD_IN
FEEDBACK
DIST

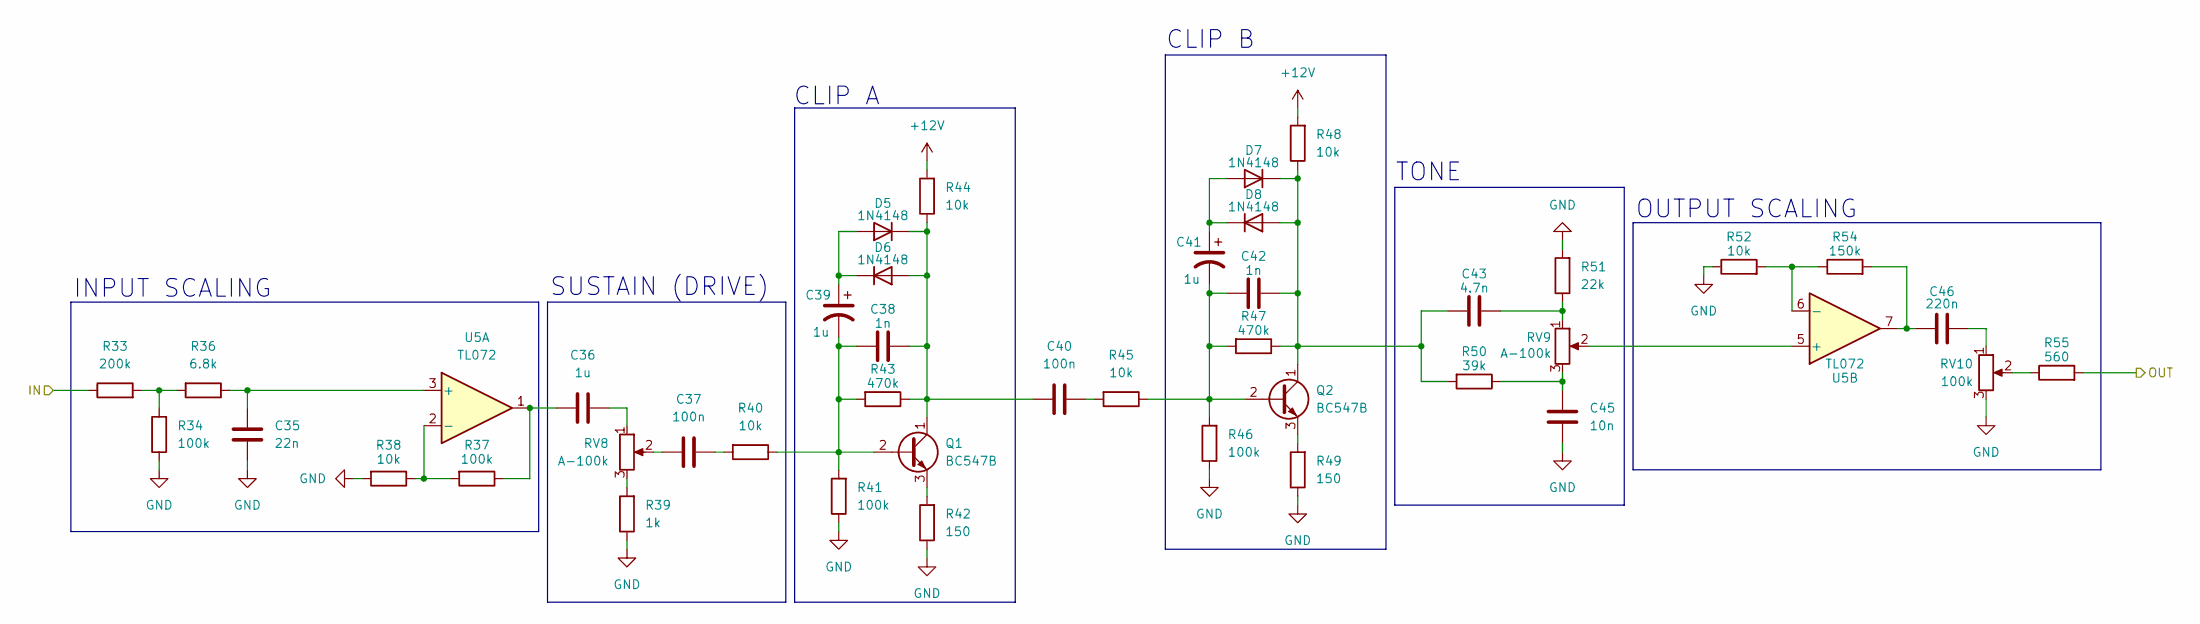
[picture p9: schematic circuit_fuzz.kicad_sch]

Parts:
C35: 22n; C_0805_2012Metric_Pad1.18x1.45mm_HandSolder
C36: 1u; C_0805_2012Metric_Pad1.18x1.45mm_HandSolder
C37, C40: 100n; C_0805_2012Metric_Pad1.18x1.45mm_HandSolder
C38, C42: 1n; C_0805_2012Metric_Pad1.18x1.45mm_HandSolder
C39, C41: 1u; CP_Radial_D4.0mm_P1.50mm
C43: 4.7n; C_0805_2012Metric_Pad1.18x1.45mm_HandSolder
C45: 10n; C_0805_2012Metric_Pad1.18x1.45mm_HandSolder
C46: 220n; C_0805_2012Metric_Pad1.18x1.45mm_HandSolder
D5, D6, D7, D8: 1N4148; D_SOD-323
Q1, Q2: BC547B; TO-92_Inline
R33: 200k; R_0805_2012Metric_Pad1.20x1.40mm_HandSolder
R34, R37, R41, R46: 100k; R_0805_2012Metric_Pad1.20x1.40mm_HandSolder
R36: 6.8k; R_0805_2012Metric_Pad1.20x1.40mm_HandSolder
R38, R40, R44, R45, R48, R52: 10k; R_0805_2012Metric_Pad1.20x1.40mm_HandSolder
R39: 1k; R_0805_2012Metric_Pad1.20x1.40mm_HandSolder
R42, R49: 150; R_0805_2012Metric_Pad1.20x1.40mm_HandSolder
R43, R47: 470k; R_0805_2012Metric_Pad1.20x1.40mm_HandSolder
R50: 39k; R_0805_2012Metric_Pad1.20x1.40mm_HandSolder
R51: 22k; R_0805_2012Metric_Pad1.20x1.40mm_HandSolder
R54: 150k; R_0805_2012Metric_Pad1.20x1.40mm_HandSolder
R55: 560; R_0805_2012Metric_Pad1.20x1.40mm_HandSolder
RV8, RV9: A-100k; Potentiometer_Alps_RK09K_Single_Vertical
RV10: 100k; Potentiometer_Alps_RK09K_Single_Vertical
U5: TL072; D8_TEX_STM

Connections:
+12V: R44.2, R48.2; also elsewhere on the board
/FUZZ Circuit/IN: R33.1; also elsewhere on the board
/FUZZ Circuit/OUT: R55.2; also elsewhere on the board
GND: C35.1, C45.1, R34.1, R38.2, R39.1, R41.1, R42.1, R46.1, R49.1, R51.2, R52.1, RV10.3; also elsewhere on the board
unnamed: C36.1, R37.1, U5.1
unnamed: C36.2, RV8.1
unnamed: C37.1, RV8.2
unnamed: C37.2, R40.2
unnamed: C40.2, R45.2
unnamed: C43.2, R51.1, RV9.1
unnamed: C45.2, R50.1, RV9.3
unnamed: C46.1, R54.2, U5.7
unnamed: C46.2, RV10.1
unnamed: C39.1, D5.2 (A), D6.1 (K)
unnamed: C38.2, C40.1, D5.1 (K), D6.2 (A), Q1.1 (C), R43.1, R44.1
unnamed: C41.1, D7.2 (A), D8.1 (K)
unnamed: C42.2, C43.1, D7.1 (K), D8.2 (A), Q2.1 (C), R47.1, R48.1, R50.2
unnamed: C38.1, C39.2, Q1.2 (B), R40.1, R41.2, R43.2
unnamed: Q1.3 (E), R42.2
unnamed: C41.2, C42.1, Q2.2 (B), R45.1, R46.2, R47.2
unnamed: Q2.3 (E), R49.2
unnamed: R33.2, R34.2, R36.2
unnamed: R39.2, RV8.3
unnamed: R55.1, RV10.2
unnamed: C35.2, R36.1, U5.3 (+)
unnamed: R37.2, R38.1, U5.2 (-)
unnamed: RV9.2, U5.5 (+)
unnamed: R52.2, R54.1, U5.6 (-)

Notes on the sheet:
SUSTAIN (DRIVE)
TONE
CLIP B
OUTPUT SCALING
CLIP A
INPUT SCALING

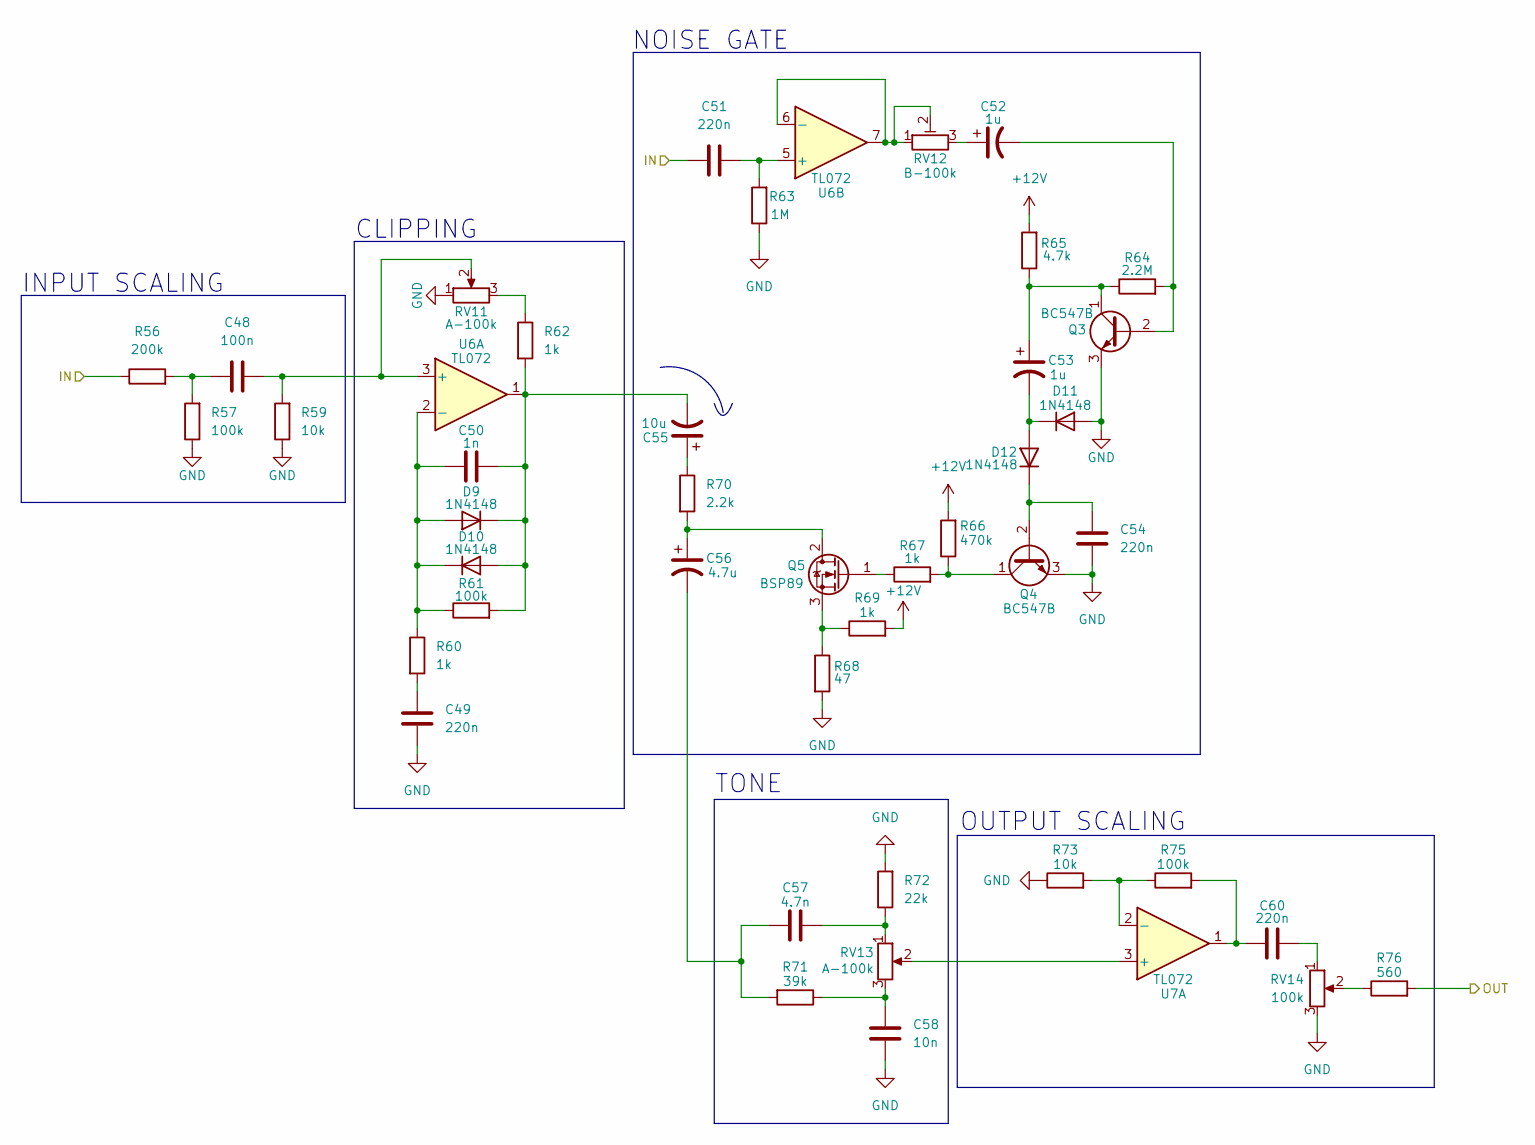
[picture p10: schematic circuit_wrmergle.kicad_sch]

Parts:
C48: 100n; C_0805_2012Metric_Pad1.18x1.45mm_HandSolder
C49, C51, C54, C60: 220n; C_0805_2012Metric_Pad1.18x1.45mm_HandSolder
C50: 1n; C_0805_2012Metric_Pad1.18x1.45mm_HandSolder
C52, C53: 1u; CP_Radial_D4.0mm_P1.50mm
C55: 10u; CP_Radial_D4.0mm_P1.50mm
C56: 4.7u; CP_Radial_D4.0mm_P1.50mm
C57: 4.7n; C_0805_2012Metric_Pad1.18x1.45mm_HandSolder
C58: 10n; C_0805_2012Metric_Pad1.18x1.45mm_HandSolder
D9, D10, D11, D12: 1N4148; D_SOD-323
Q3, Q4: BC547B; TO-92_Inline
Q5: BSP89; SOT-223-3_TabPin2
R56: 200k; R_0805_2012Metric_Pad1.20x1.40mm_HandSolder
R57, R61, R75: 100k; R_0805_2012Metric_Pad1.20x1.40mm_HandSolder
R59, R73: 10k; R_0805_2012Metric_Pad1.20x1.40mm_HandSolder
R60, R62, R67, R69: 1k; R_0805_2012Metric_Pad1.20x1.40mm_HandSolder
R63: 1M; R_0805_2012Metric_Pad1.20x1.40mm_HandSolder
R64: 2.2M; R_0805_2012Metric_Pad1.20x1.40mm_HandSolder
R65: 4.7k; R_0805_2012Metric_Pad1.20x1.40mm_HandSolder
R66: 470k; R_0805_2012Metric_Pad1.20x1.40mm_HandSolder
R68: 47; R_0805_2012Metric_Pad1.20x1.40mm_HandSolder
R70: 2.2k; R_0805_2012Metric_Pad1.20x1.40mm_HandSolder
R71: 39k; R_0805_2012Metric_Pad1.20x1.40mm_HandSolder
R72: 22k; R_0805_2012Metric_Pad1.20x1.40mm_HandSolder
R76: 560; R_0805_2012Metric_Pad1.20x1.40mm_HandSolder
RV11, RV13: A-100k; Potentiometer_Alps_RK09K_Single_Vertical
RV12: B-100k; TRIM_3362P-1-253LF
RV14: 100k; Potentiometer_Alps_RK09K_Single_Vertical
U6, U7: TL072; D8_TEX_STM

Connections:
+12V: R65.2, R66.2, R69.2; also elsewhere on the board
/WRMERGLE Circuit/IN: C51.1, R56.1; also elsewhere on the board
/WRMERGLE Circuit/OUT: R76.2; also elsewhere on the board
GND: C49.2, C54.1, C58.1, D11.2 (A), Q3.3 (E), Q4.3 (E), R57.1, R59.1, R63.1, R68.2, R72.2, R73.1, RV11.1, RV14.3; also elsewhere on the board
unnamed: C48.1, R56.2, R57.2
unnamed: C49.1, R60.2
unnamed: C52.1, RV12.3
unnamed: C55.1, R70.1
unnamed: C56.2, C57.1, R71.2
unnamed: C57.2, R72.1, RV13.1
unnamed: C58.2, R71.1, RV13.3
unnamed: C60.1, R75.2, U7.1
unnamed: C60.2, RV14.1
unnamed: C50.2, C55.2, D9.1 (K), D10.2 (A), R61.2, R62.2, U6.1
unnamed: C50.1, D9.2 (A), D10.1 (K), R60.1, R61.1, U6.2 (-)
unnamed: C53.2, D11.1 (K), D12.2 (A)
unnamed: C54.2, D12.1 (K), Q4.2 (B)
unnamed: C52.2, Q3.2 (B), R64.2
unnamed: C53.1, Q3.1 (C), R64.1, R65.1
unnamed: Q4.1 (C), R66.1, R67.2
unnamed: C56.1, Q5.2 (D), R70.2
unnamed: Q5.1 (G), R67.1
unnamed: Q5.3 (S), R68.1, R69.1
unnamed: R62.1, RV11.3
unnamed: R76.1, RV14.2
unnamed: C48.2, R59.2, RV11.2, U6.3 (+)
unnamed: C51.2, R63.2, U6.5 (+)
unnamed: RV12.1, RV12.2, U6.6 (-), U6.7
unnamed: RV13.2, U7.3 (+)
unnamed: R73.2, R75.1, U7.2 (-)

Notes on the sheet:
NOISE GATE
CLIPPING
TONE
INPUT SCALING
OUTPUT SCALING

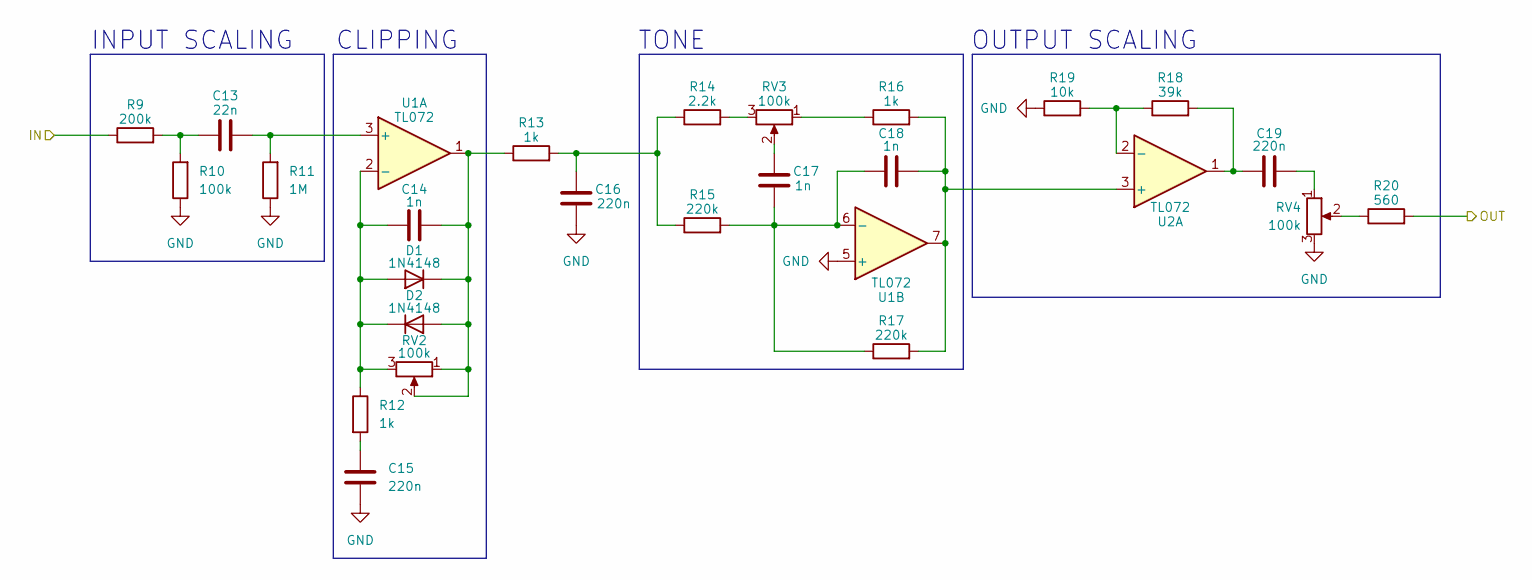
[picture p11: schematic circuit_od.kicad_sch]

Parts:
C13: 22n; C_0805_2012Metric_Pad1.18x1.45mm_HandSolder
C14, C17, C18: 1n; C_0805_2012Metric_Pad1.18x1.45mm_HandSolder
C15, C16, C19: 220n; C_0805_2012Metric_Pad1.18x1.45mm_HandSolder
D1, D2: 1N4148; D_SOD-323
R9: 200k; R_0805_2012Metric_Pad1.20x1.40mm_HandSolder
R10: 100k; R_0805_2012Metric_Pad1.20x1.40mm_HandSolder
R11: 1M; R_0805_2012Metric_Pad1.20x1.40mm_HandSolder
R12, R13, R16: 1k; R_0805_2012Metric_Pad1.20x1.40mm_HandSolder
R14: 2.2k; R_0805_2012Metric_Pad1.20x1.40mm_HandSolder
R15, R17: 220k; R_0805_2012Metric_Pad1.20x1.40mm_HandSolder
R18: 39k; R_0805_2012Metric_Pad1.20x1.40mm_HandSolder
R19: 10k; R_0805_2012Metric_Pad1.20x1.40mm_HandSolder
R20: 560; R_0805_2012Metric_Pad1.20x1.40mm_HandSolder
RV2, RV3, RV4: 100k; Potentiometer_Alps_RK09K_Single_Vertical
U1, U2: TL072; D8_TEX_STM

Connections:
/OD Circuit/IN: R9.1; also elsewhere on the board
/OD Circuit/OUT: R20.2; also elsewhere on the board
GND: C15.2, C16.2, R10.1, R11.1, R19.1, RV4.3, U1.5 (+); also elsewhere on the board
unnamed: C13.1, R9.2, R10.2
unnamed: C15.1, R12.2
unnamed: C16.1, R13.2, R14.1, R15.1
unnamed: C17.1, RV3.2
unnamed: C19.1, R18.2, U2.1
unnamed: C19.2, RV4.1
unnamed: C14.1, D1.2 (A), D2.1 (K), R12.1, RV2.3, U1.2 (-)
unnamed: C14.2, D1.1 (K), D2.2 (A), R13.1, RV2.1, RV2.2, U1.1
unnamed: R14.2, RV3.3
unnamed: R16.1, RV3.1
unnamed: R20.1, RV4.2
unnamed: C13.2, R11.2, U1.3 (+)
unnamed: C17.2, C18.1, R15.2, R17.1, U1.6 (-)
unnamed: C18.2, R16.2, R17.2, U1.7, U2.3 (+)
unnamed: R18.1, R19.2, U2.2 (-)

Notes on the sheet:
TONE
CLIPPING
OUTPUT SCALING
INPUT SCALING

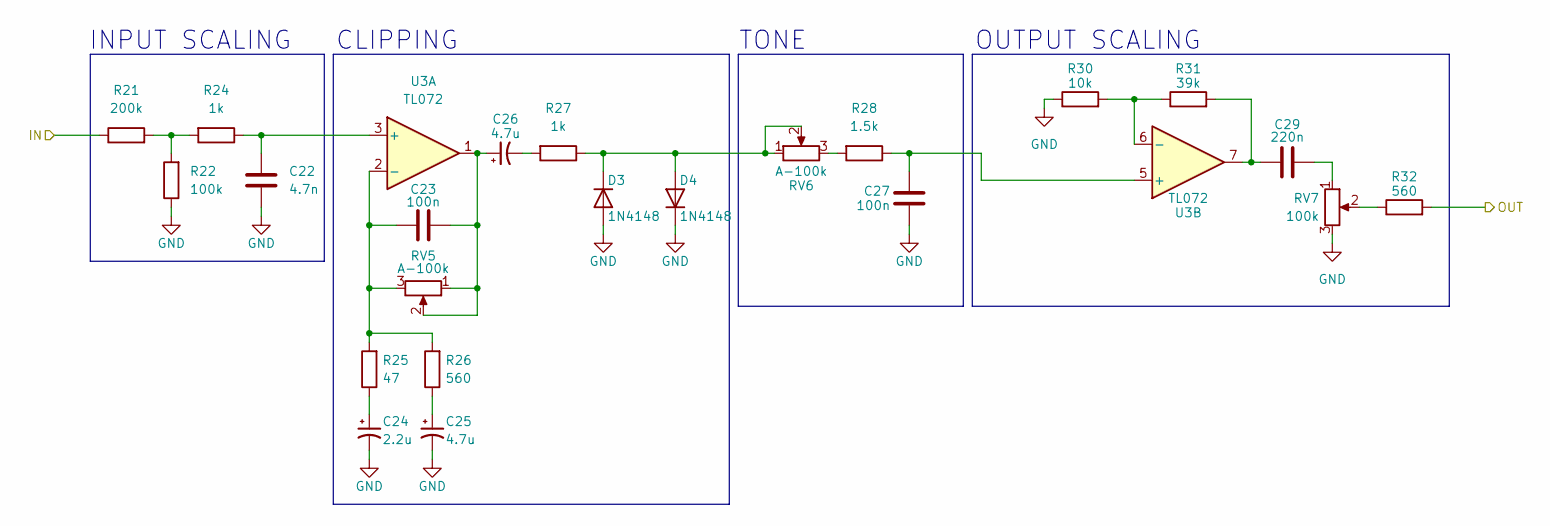
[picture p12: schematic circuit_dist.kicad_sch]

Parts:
C22: 4.7n; C_0805_2012Metric_Pad1.18x1.45mm_HandSolder
C23, C27: 100n; C_0805_2012Metric_Pad1.18x1.45mm_HandSolder
C24: 2.2u; CP_Radial_D4.0mm_P1.50mm
C25, C26: 4.7u; CP_Radial_D4.0mm_P1.50mm
C29: 220n; C_0805_2012Metric_Pad1.18x1.45mm_HandSolder
D3, D4: 1N4148; D_SOD-323
R21: 200k; R_0805_2012Metric_Pad1.20x1.40mm_HandSolder
R22: 100k; R_0805_2012Metric_Pad1.20x1.40mm_HandSolder
R24, R27: 1k; R_0805_2012Metric_Pad1.20x1.40mm_HandSolder
R25: 47; R_0805_2012Metric_Pad1.20x1.40mm_HandSolder
R26, R32: 560; R_0805_2012Metric_Pad1.20x1.40mm_HandSolder
R28: 1.5k; R_0805_2012Metric_Pad1.20x1.40mm_HandSolder
R30: 10k; R_0805_2012Metric_Pad1.20x1.40mm_HandSolder
R31: 39k; R_0805_2012Metric_Pad1.20x1.40mm_HandSolder
RV5, RV6: A-100k; Potentiometer_Alps_RK09K_Single_Vertical
RV7: 100k; Potentiometer_Alps_RK09K_Single_Vertical
U3: TL072; D8_TEX_STM

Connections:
/DIST Circuit/IN: R21.1; also elsewhere on the board
/DIST Circuit/OUT: R32.2; also elsewhere on the board
GND: C22.1, C24.2, C25.2, C27.1, D3.2 (A), D4.1 (K), R22.1, R30.1, RV7.3; also elsewhere on the board
unnamed: C23.2, C26.1, RV5.1, RV5.2, U3.1
unnamed: C24.1, R25.1
unnamed: C25.1, R26.1
unnamed: C26.2, R27.2
unnamed: C29.1, R31.2, U3.7
unnamed: C29.2, RV7.1
unnamed: D3.1 (K), D4.2 (A), R27.1, RV6.1, RV6.2
unnamed: R21.2, R22.2, R24.2
unnamed: R28.2, RV6.3
unnamed: R32.1, RV7.2
unnamed: C22.2, R24.1, U3.3 (+)
unnamed: C23.1, R25.2, R26.2, RV5.3, U3.2 (-)
unnamed: C27.2, R28.1, U3.5 (+)
unnamed: R30.2, R31.1, U3.6 (-)

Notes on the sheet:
INPUT SCALING
TONE
OUTPUT SCALING
CLIPPING

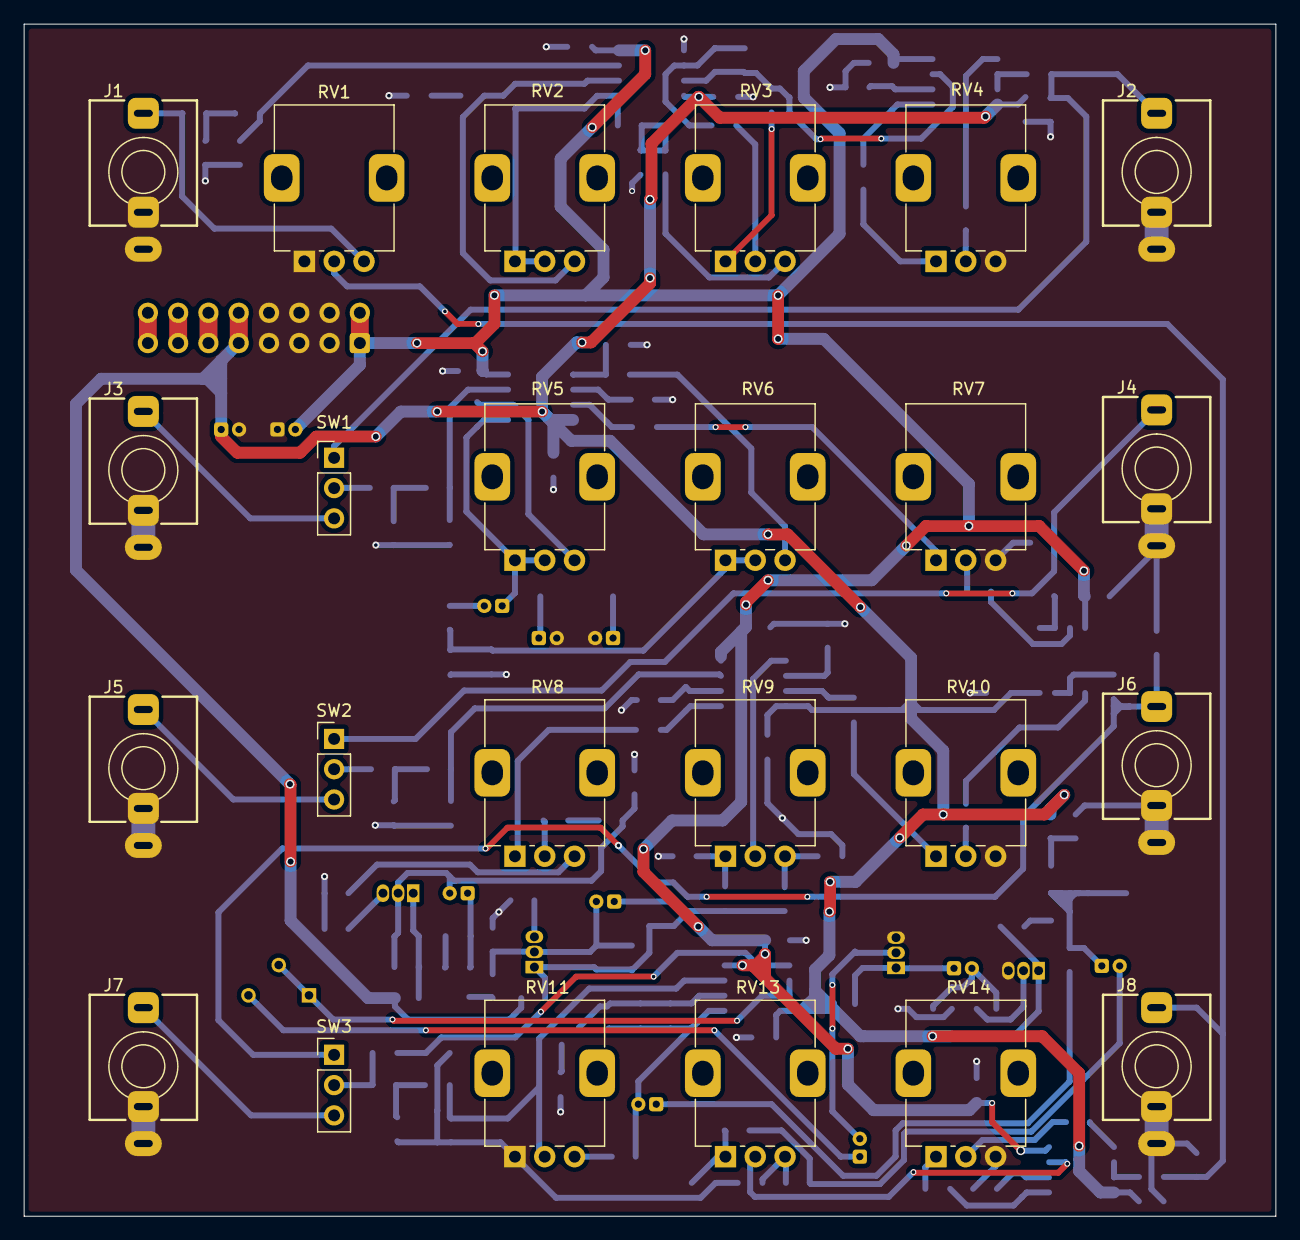
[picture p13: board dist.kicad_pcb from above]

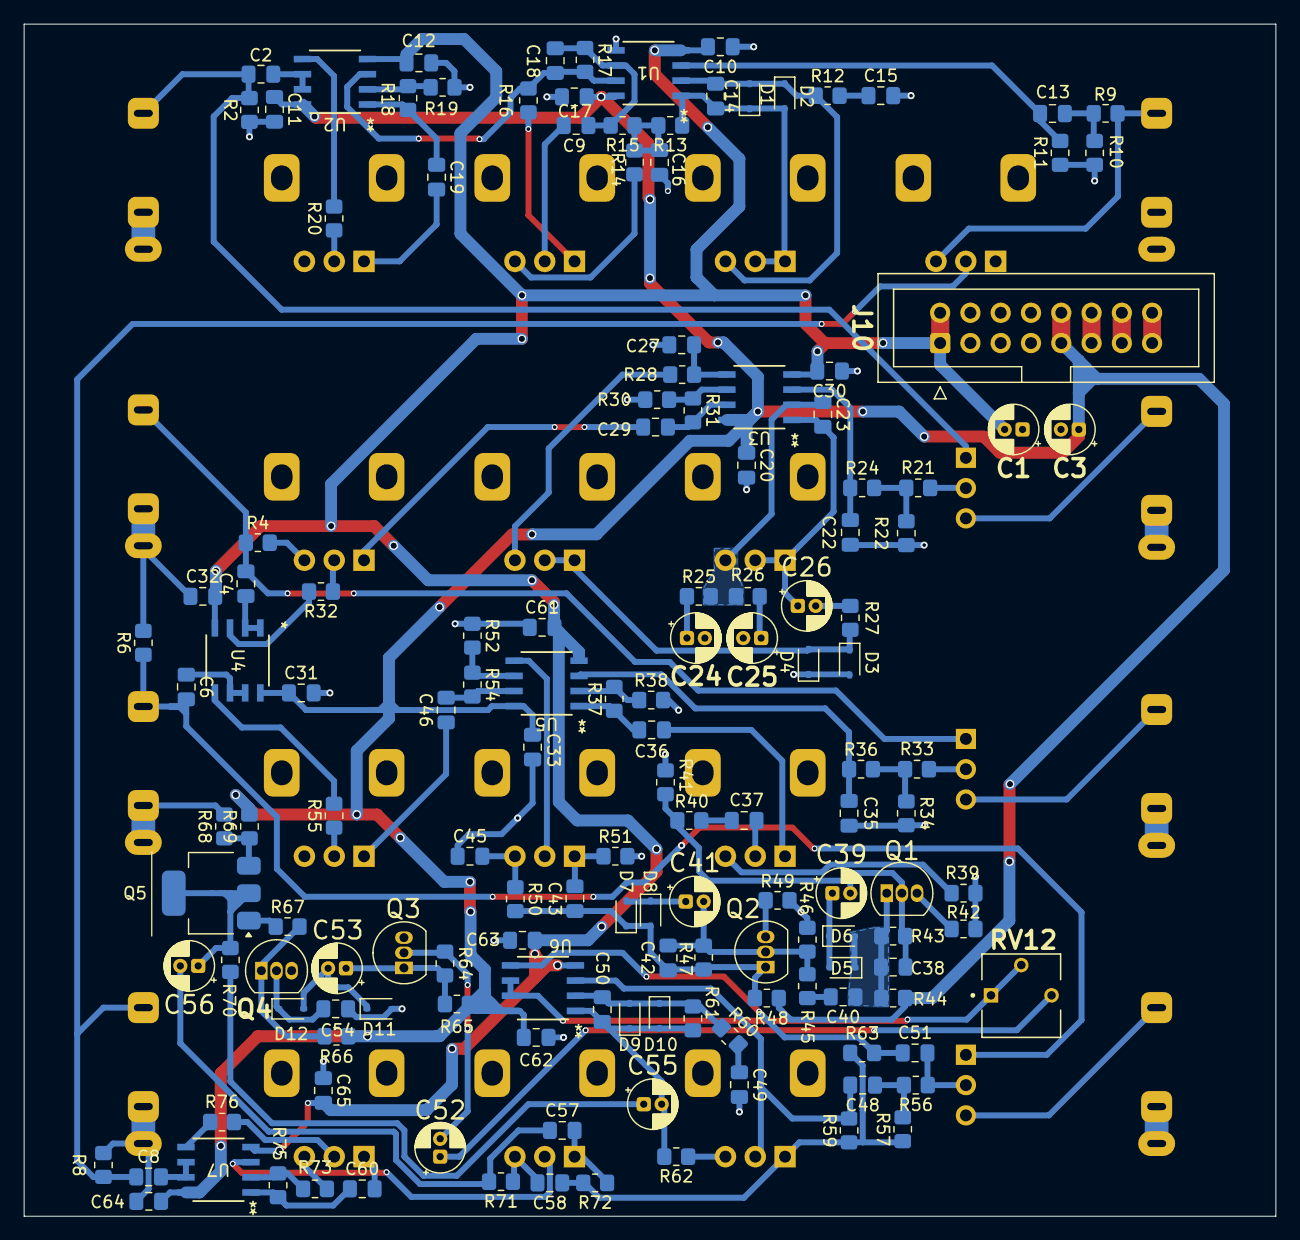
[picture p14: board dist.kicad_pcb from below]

Board: 2 copper layers, 105.0 x 100.0 mm, 173 parts (149 on the bottom side), 101 nets.

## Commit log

2026-05-17 new circuits
    Former-commit-id: 70c6545935585a71ad606ec7b30507693d0ee072
2026-06-01 bom + kicad fix for dual supply
    [bom.ods, circuit_dist.kicad_sch, circuit_fuzz.kicad_sch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]
2026-06-01 Libreoffice gitignore, bom
    [dist.kicad_pcb]
2026-06-02 finish pcb
    [circuit_dist.kicad_sch, circuit_fuzz.kicad_sch, circuit_od.kicad_sch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]
2026-06-03 audio samples
2026-06-07 add schematics to readme
